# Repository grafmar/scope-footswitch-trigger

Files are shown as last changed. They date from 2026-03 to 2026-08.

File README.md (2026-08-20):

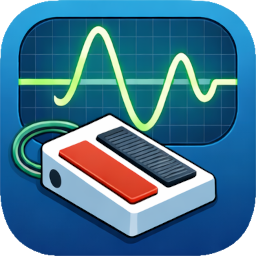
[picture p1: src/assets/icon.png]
Application icon
# Scope Footswitch Trigger 





Scope Footswitch Trigger enables hands-free control of an oscilloscope using a dual footswitch connected through an Arduino Nano.

The Arduino detects short and long presses on two foot pedals and sends events via USB (Serial) to a PC. A Python application running in the background receives these events and remotely controls the oscilloscope over LAN using SCPI commands.

This setup is ideal for lab environments where both hands are occupied — for example during probing, debugging hardware, or EMC measurements.

## 🧪 Usage
<p align="center">
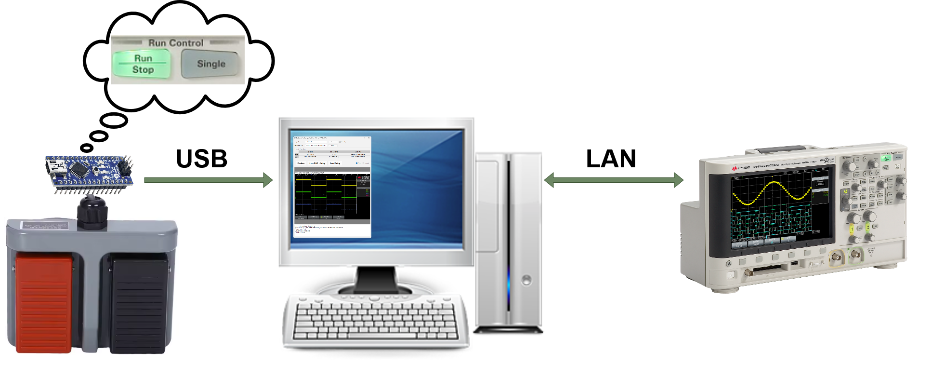
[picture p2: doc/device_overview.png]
Device overview
  
</p>

- Connect the dual footswitch to the PC via USB.
- Connect the oscilloscope to the network and obtain its IP address (via Utility → I/O on the Keysight/Agilent oscilloscope).
  - Activate VX11 on LeCroy oscilloscopes
- Start `OsciFootswitch.exe` (or `python OsciFootswitch.py`).
- Enter the oscilloscope’s IP address and click **\<Connect\>**.
- Use the "Identify Oscilloscope" checkbox to display a text box on the oscilloscope screen to verify the correct device.
- Select the correct serial port of the footswitch (identifier "USB-Serial CH340") and click **\<Open\>**.

→ The footswitch is ready.

## 🎯 Features
- Detects short and long presses for both pedals individually and if both are pressed at the same time
- Remote oscilloscope control via LAN
- Trigger control:
  - RUN / START
  - STOP
  - SINGLE (Single Shot)
- Toggle between:
  - Normal Trigger Mode
  - Auto Trigger Mode
- Capture and store:
  - Screenshot
  - Oscilloscope setup

## ⚙️ How It Works
1. The Arduino monitors two input pins connected to a dual footswitch.
2. Short and long presses are detected directly on the Arduino.
3. Events are sent via USB Serial (e.g. B1S, B1L, B2S, B2L, BBS, BBL).
4. The Python application:
  - Opens the configured serial port
  - Connects to the oscilloscope via IP (LAN)
  - Maps footswitch events to SCPI commands
5. The oscilloscope executes the corresponding trigger or screenshot command.

## 🤖 Hardware
A dual footswitch is connected to an Arduino Nano. The left switch connects to D3 and the right switch to D4 of the Arduino Nano. The switches connect to GND.

That's all for the hardware. The Arduino is powered and connected to a PC through its USB connector. [Detailed HW build](doc/hw/README.md) for more information.

The Arduino code `footswitch.ino` debounces the switch events, detects short and long presses and sends the corresponding event string through USB-serial.

<p align="center">
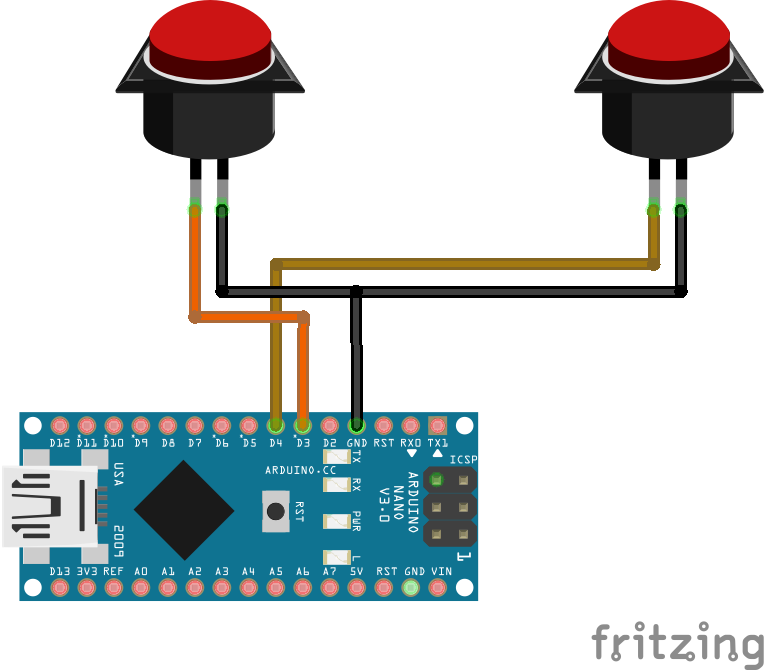
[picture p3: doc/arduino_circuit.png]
Hardware circuit
  
</p>

## 👨‍💻 Software
The PC application is compiled from a Ppython script. If you want to adapt the code, you have to install several Python packages, which are listed in `src/pc_app/requirements.txt`. You can apply them by:
```bash
pip install -r requirements.txt
```

To compile the Python to a Windows EXE file including all the necessary libraries you can simply execute the batch file:
```bash
.\src\build_scripts\build.bat
```
→ The EXE will be available at `.\src\build_scripts\dist\OsciFootswitch\OsciFootswitch.exe`

### 🏗️ SW-Architecture
<p align="center">
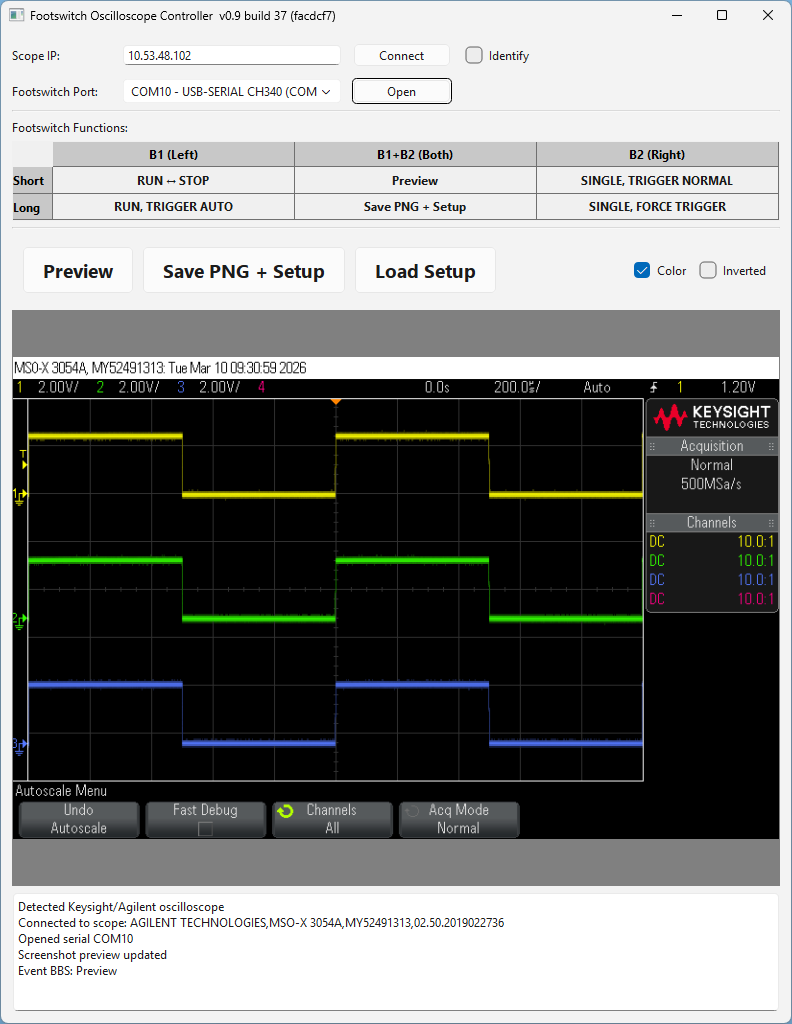
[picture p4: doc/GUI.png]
GUI
  
</p>
The GUI has the configuration part at the top, then a part that explains the footswitch function mappings. Below that is the screenshot section and at the bottom the log.

Upon connecting to the oscilloscope's IP the common SCPI/VISA identifier command `*IDN?` is used to identify the manufacturer and type of the oscilloscope. Depending on that identifier string the corresponding implementation for that oscilloscope is used. If the brand is not recognized the Keysight/Agilent implementation is used.

When the serial port of the footswitch is configured, the incoming events on the serial port are mapped to the corresponding oscilloscope functions and the SCPI/VISA commands are sent to the oscilloscope.

When a screenshot is captured, a setup file is also stored with the same basename. This setup file can then be reapplied to the scope later if needed.

### 📻 Supported Oscilloscopes
- ✅ Keysight/Agilent 2000 X-Series (DSOX2004A)
- ✅ Keysight/Agilent 3000 X-Series (MSOX3054A)
- ✅ Keysight/Agilent 4000 X-series (MSOX4024A)
- ✅ Keysight/Agilent 6000 X-series (DSOX6004A)
- ✅ Keysight/Agilent 7000 Series (MSO7054A)
- ✅ LeCroy Waverunner 6100
- ✅ LeCroy Waverunner 44XI
- ❌ Hameg/R&S HMO3000 Series (HMO3524) [documentation](doc/HMO3524_documentation.md)

SCPI/VISA Documentations:
- [2000 X-Series Programmer's Guide](https://www.keysight.com/us/en/assets/9018-06893/programming-guides/9018-06893.pdf)
- [3000 X-Series Programmer's Guide](https://www.keysight.com/us/en/assets/9018-06894/programming-guides/9018-06894.pdf)
- [4000 X-Series Programmer's Guide](https://www.keysight.com/us/en/assets/9018-06976/programming-guides/9018-06976.pdf)
- [6000 Series Programmer's Guide](https://www.keysight.com/ch/de/assets/9018-08107/programming-guides/9018-08107.pdf)
- [7000A Series Programmer's Guide](https://www.keysight.com/us/en/assets/9018-06630/programming-guides/9018-06630.pdf)
- [Waverunner Remote Control Manual](https://cdn.teledynelecroy.com/files/manuals/wr2_rcm_revb.pdf) 
- [Hameg/R&S HMO3000 Series SCPI Programmers Manual](https://www.batronix.com/files/Rohde-%26-Schwarz/Oscilloscope/HMO30xx/HMO3000_ProgrammingManual_en.pdf)

## 🚀 Advantages and Example Use Cases
- Hands-free operation → Trigger a single acquisition while holding probes
- Quickly toggle between Auto and Normal trigger during debugging
- Capture a screenshot including instrument setup without touching the scope
- Improve workflow in production test environments
- Minimal hardware cost
- Works in the background
- No modification of the oscilloscope required
- Fully scriptable and extendable

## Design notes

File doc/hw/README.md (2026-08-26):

# Footswitch Hardware

This project uses an off-the-shelf dual footswitch combined with an Arduino Nano to provide two USB-connected footswitch inputs for the PC application.

A custom 3D-printed enclosure houses the Arduino Nano and a small interface PCB and is mounted directly to the footswitch.

<p align="center">
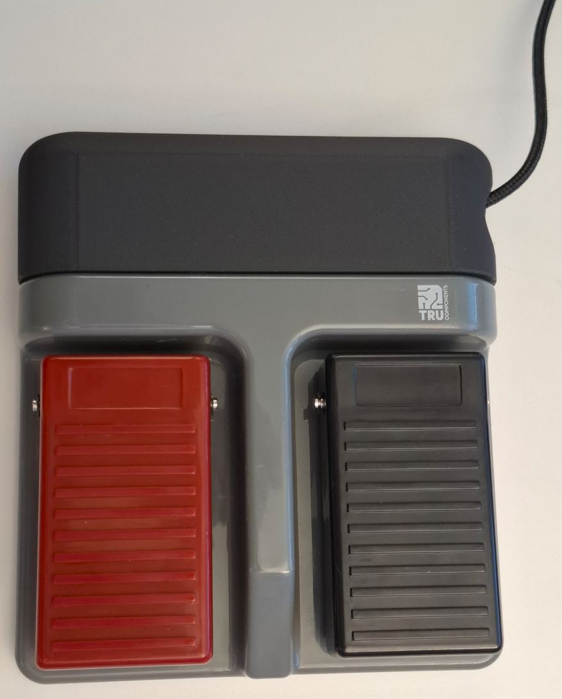
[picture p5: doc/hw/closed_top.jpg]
Footswitch – closed, top view
  
</p>

## Required Hardware

* Dual footswitch — TRU COMPONENTS TC-6648040, available from [Conrad.ch](https://www.conrad.ch/de/p/tru-components-fussschalter-250-v-ac-16-a-2-pedale-2-oeffner-2-schliesser-1-st-1662010.html)

  * Other similar dual footswitches can also be used, for example from [AliExpress](https://de.aliexpress.com/w/wholesale-double-footswitch.html)
* Arduino Nano
* Female pin headers for Arduino Nano
* Molex KK 254, 4-pin, right-angle header (Molex 22-05-7048)
* Matching Molex KK 254 connector housing with crimp contacts
* Stripboard / veroboard, or a custom PCB
* Wires
* M3 bolts and nuts
  * 4x M3x6 Cylinder Head
  * 4x M3x20 Cylinder Head
  * 2x M3x6 Lens Head
  * 2x M3 Lock Nut
* 8x Press-in threaded M3 inserts ([Bossard AG, 1386743, B3/BN1054](https://www.bossard.com/ch-en/eshop/threaded-inserts-for-press-in-for-plastic-materials/press-in-threaded-inserts-without-head-for-thermoplastics-and-thermosets/p/10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))

## Interface PCB

The PCB provides the electrical connection between the footswitch and the Arduino Nano.

It contains:

* A Molex KK 254 connector for the footswitch
* An Arduino Nano mounted on female pin headers
* Four mounting holes for attaching the PCB to the enclosure

The circuit is very simple:

| Arduino | Footswitch | Function |
| --- | --- | --- |
| D3 | Left switch (red) | Left pedal  |
| D4 | Right switch (black) | Right pedal |
| GND | Switch common | Ground |

Both switches connect their respective Arduino input to GND when pressed.

<p align="center">
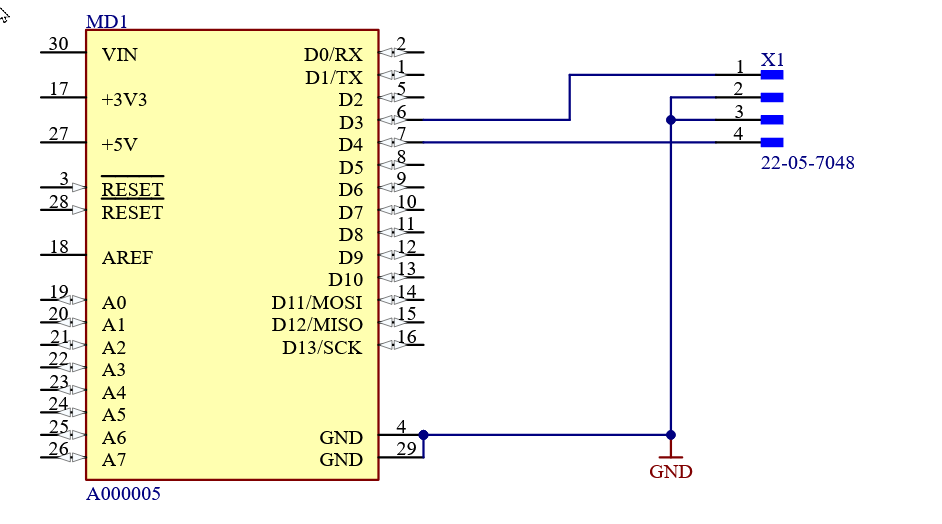
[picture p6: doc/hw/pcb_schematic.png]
PCB schematic
  
</p>

### Stripboard Version

The PCB can be built using a small piece of stripboard instead of a manufactured PCB. Nevertheless, if you want a manufactured PCB, here is the [fabrication data](../../hw/FAB-Labor_ScopeFootswitchTrigger-A0.zip).

When building the stripboard version, pay particular attention to the notch required for the screw that attaches the enclosure to the footswitch.

The following images show an example layout viewed from the top:

<p align="center">
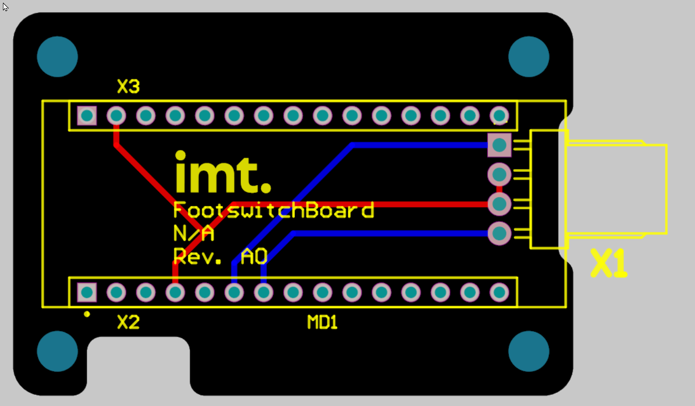
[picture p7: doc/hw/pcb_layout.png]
PCB layout
  
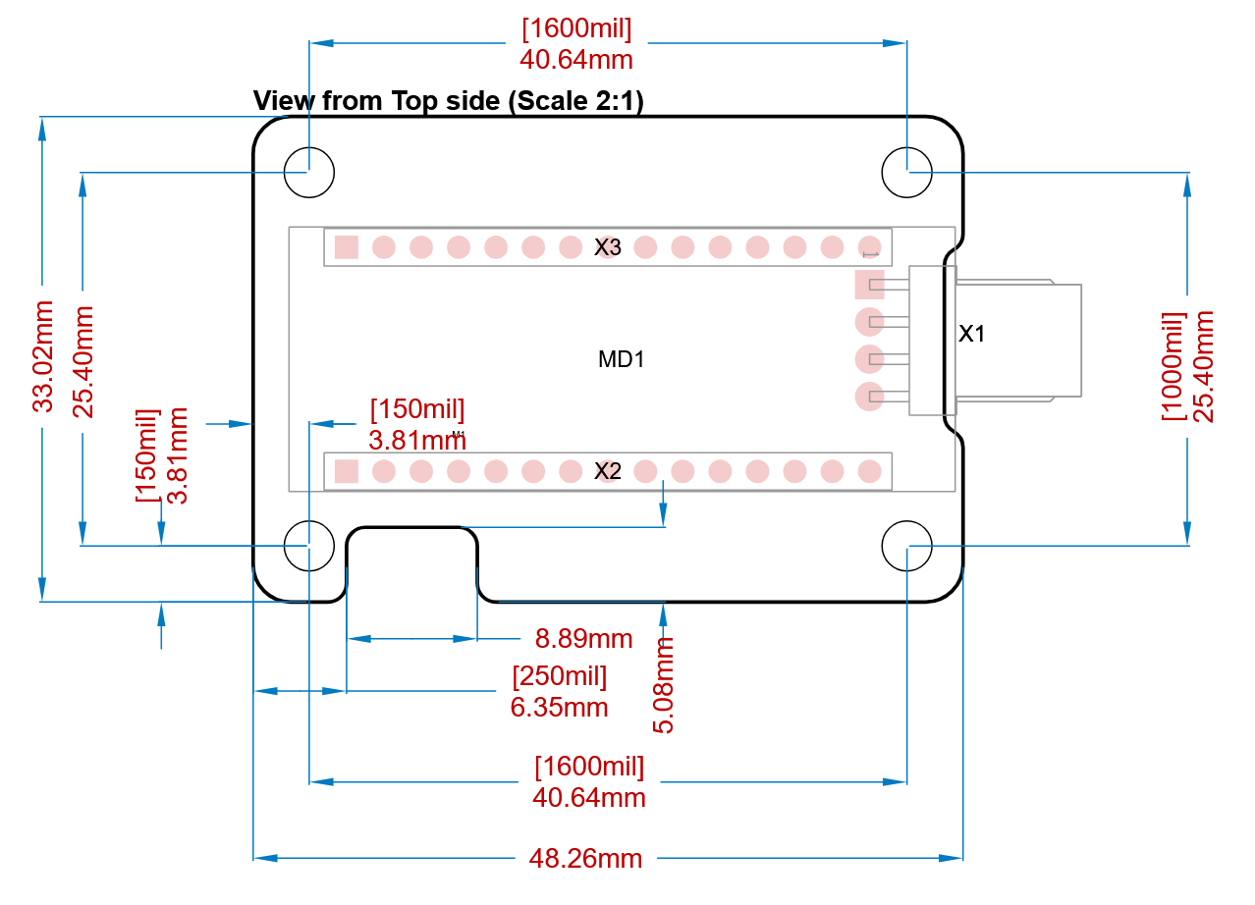
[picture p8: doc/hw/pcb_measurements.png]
PCB measurements
  
</p>
<p align="center">
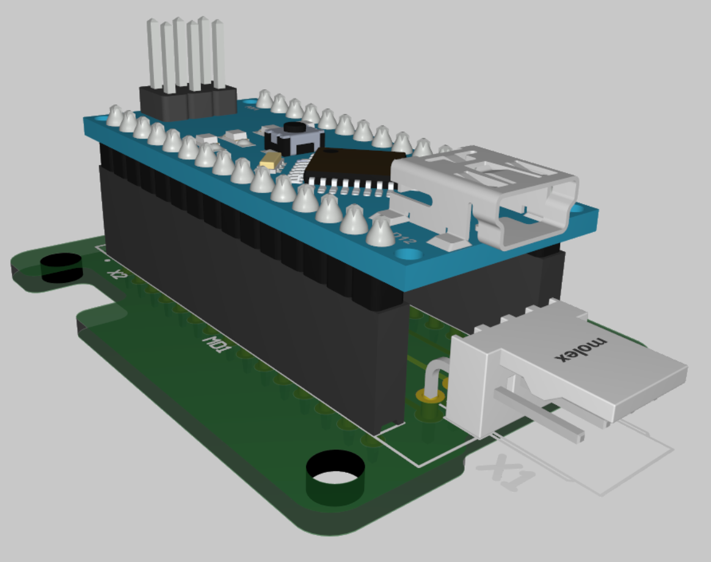
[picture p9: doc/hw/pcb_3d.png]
PCB 3D
  
</p>

## 3D-Printed Enclosure

The enclosure consists of a top and bottom part and is mounted directly to the footswitch using M3 bolts and nuts.

For the PCB and housing screws, the screw holes are designed for M3 heat-set threaded inserts. These inserts can be installed by gently melting them into the plastic using a soldering iron.

<p align="center">
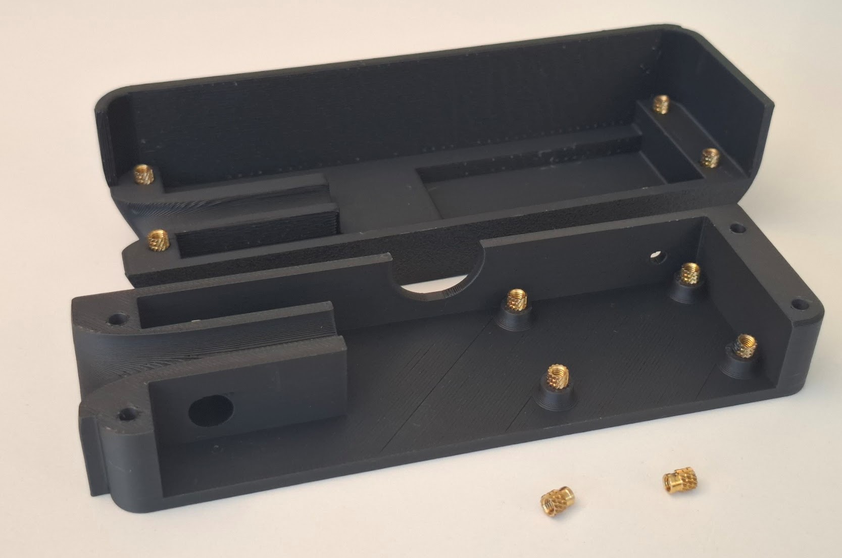
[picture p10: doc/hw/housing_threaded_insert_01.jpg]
Housing - Threaded Inserts Overview
  
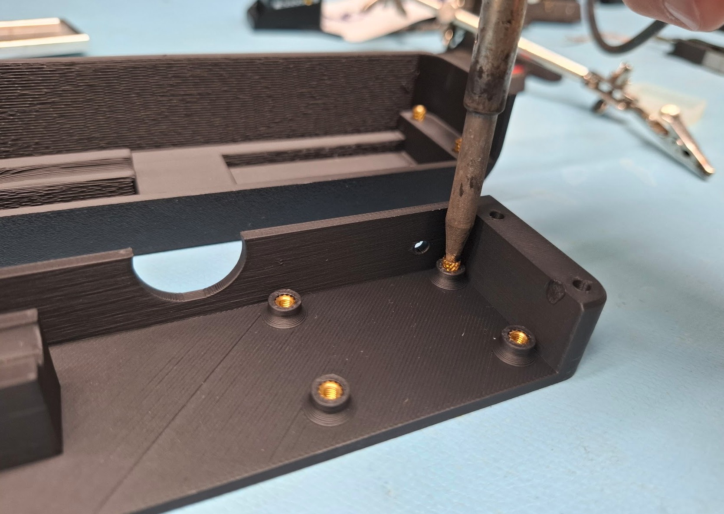
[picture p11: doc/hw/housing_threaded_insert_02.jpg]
Housing - Threaded Inserts Melting in
  
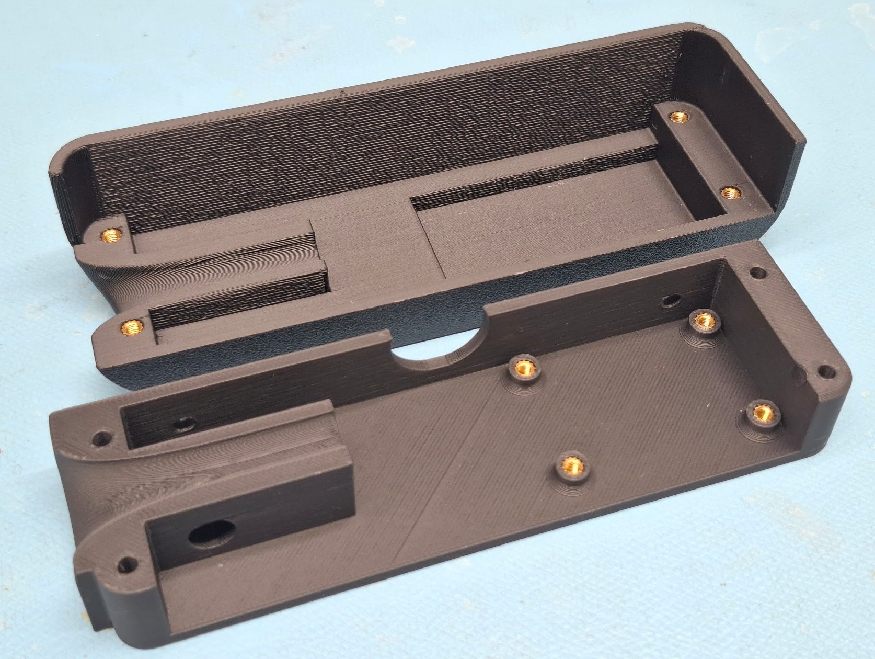
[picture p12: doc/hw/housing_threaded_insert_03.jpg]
Housing - Threaded Inserts Finished
  
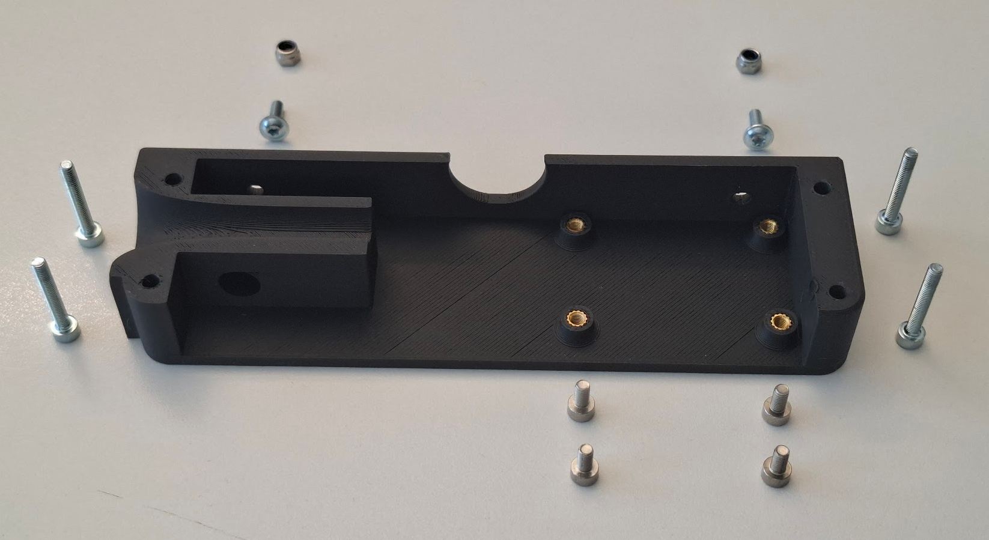
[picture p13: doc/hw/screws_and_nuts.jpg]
Screws and Nuts
  
</p>

Before mounting the enclosure, the required holes in the footswitch need to be drilled. A 3D-printed drilling jig is provided to simplify this process.

**Drilling jig:**
[OsciFootswitchHousing_DrillingJig.stl](../../housing/OsciFootswitchHousing_DrillingJig.stl)

The bottom part of the enclosure can then be mounted to the footswitch:

**Enclosure bottom:**
[OsciFootswitchHousing-BaseBodyBottom.stl](../../housing/OsciFootswitchHousing-BaseBodyBottom.stl)

The top part is attached to the bottom part using M3 bolts:

**Enclosure top:**
[OsciFootswitchHousing-BaseBodyTop.stl](../../housing/OsciFootswitchHousing-BaseBodyTop.stl)

## Assembly

The wires are soldered directly to the two footswitches and terminated with crimp contacts for the Molex KK 254 connector.

The connector is then plugged into the interface PCB, which is mounted inside the bottom part of the enclosure.

After connecting the USB cable to the Arduino Nano, the cable can be secured with a zip tie to provide strain relief.

Finally, the enclosure can be closed using the M3 bolts.

<p align="center">
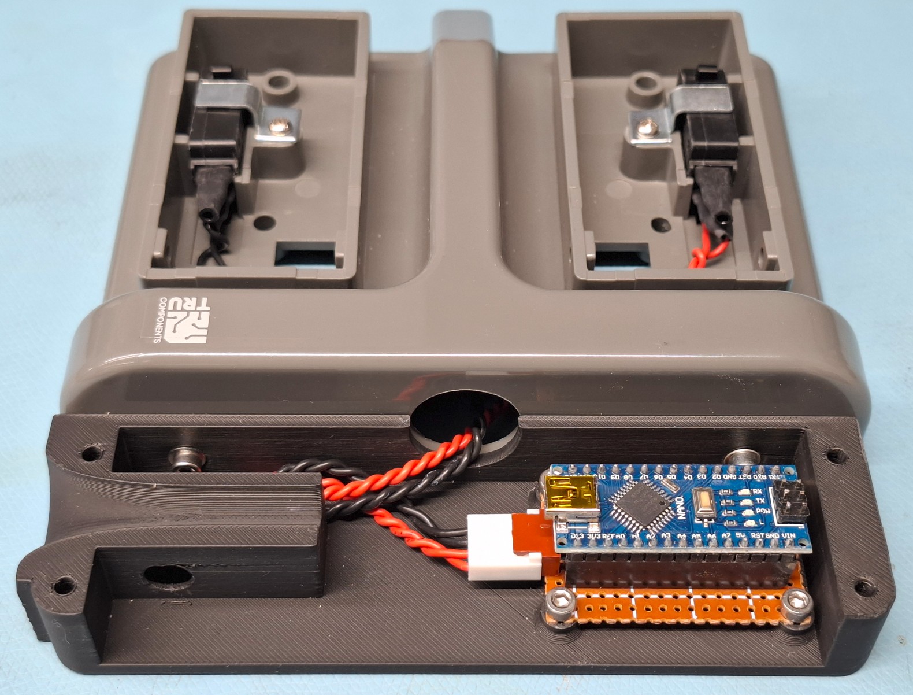
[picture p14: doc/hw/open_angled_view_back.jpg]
Footswitch – rear angled view
  
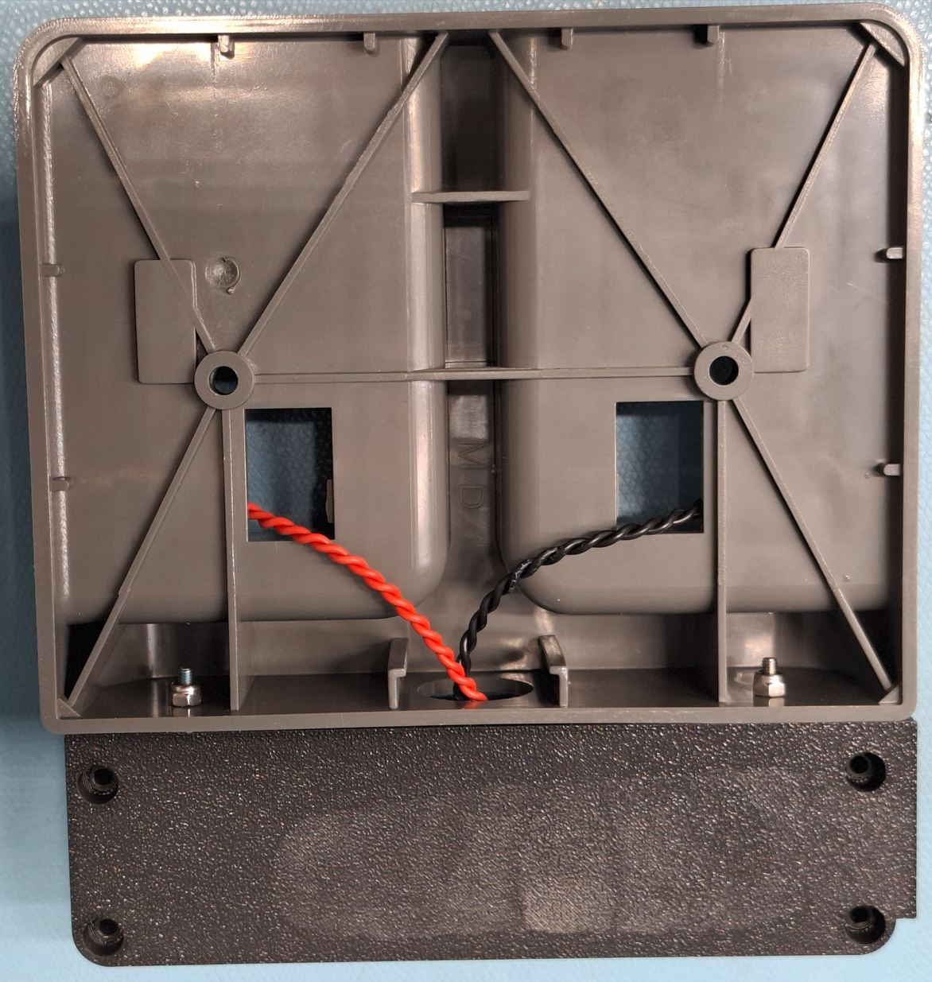
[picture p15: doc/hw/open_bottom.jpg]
Footswitch – bottom view
  
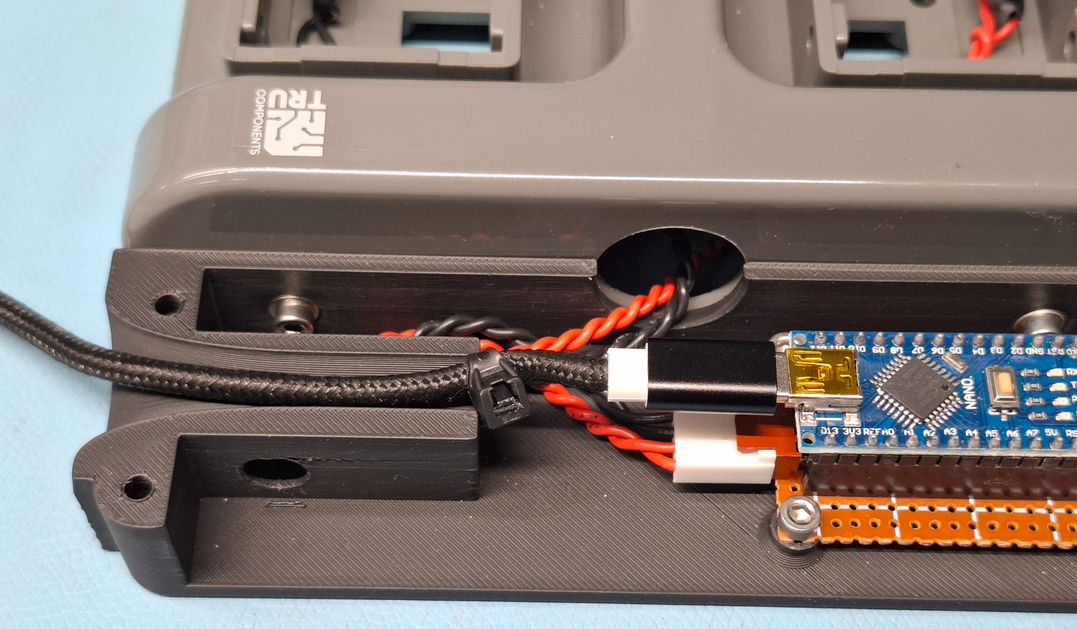
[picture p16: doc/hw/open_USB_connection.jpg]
USB connection
  
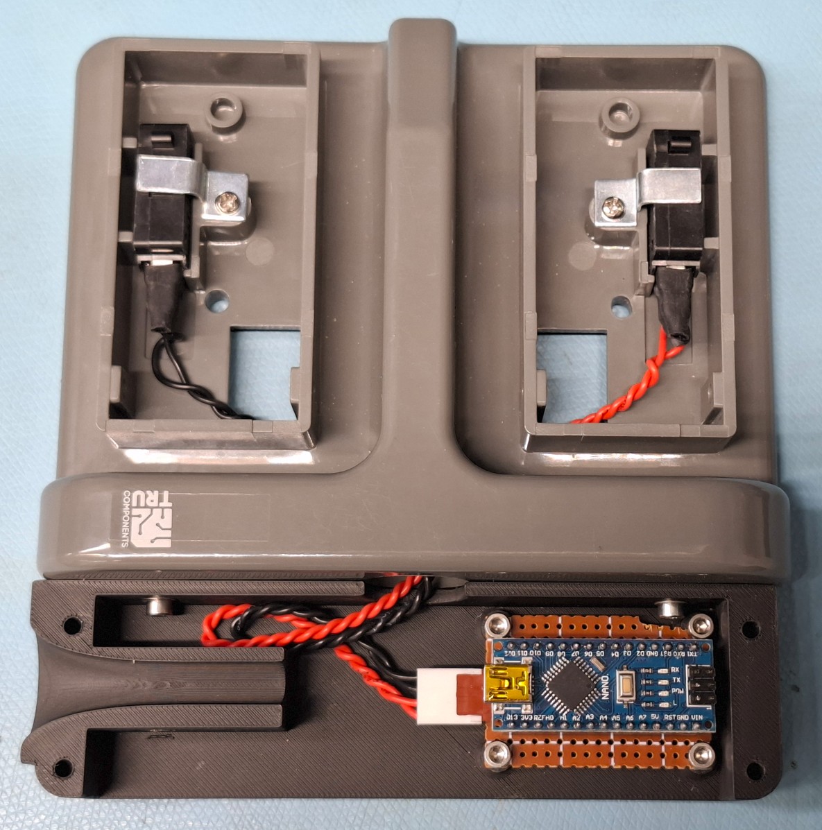
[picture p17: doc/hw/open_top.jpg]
Footswitch – top view
  
</p>

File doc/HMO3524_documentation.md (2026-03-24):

# HMO3524

## Overview
The available **HMO3524 oscilloscope** is an early hardware/firmware revision.  
Support from Hameg respectively Rhode & Schwarz for this version is very limited.

Older firmware versions and corresponding documentation are:
- difficult to find  
- often not publicly available  

As a result, reverse engineering and testing were required to evaluate SCPI support.

---

## SCPI Investigation

A custom script (`hameScpiChecker.py`) was used to:

- test known SCPI commands  
- probe undocumented commands  
- identify supported vs. unsupported functionality  

### Findings

- Only a **very limited subset of SCPI commands** is supported  
- Many standard commands (e.g. `RUN`, `STOP`, `SINGLE`) are:
  - not implemented, or  
  - ignored without proper error reporting  

- Some commands (e.g. `ACQ:TYPE`, partial `TRIG` queries) work inconsistently  

---

## Connectivity

Unlike most modern oscilloscopes, this device:

- ❌ does **not support standard VISA INSTR connections**
- ✅ is only accessible via **raw TCP socket**: `TCPIP::<IP>::50000::SOCKET`

This also leads to:

- unreliable SCPI responses  
- inconsistent error handling (`SYST:ERR?`)  
- missing or partial query replies  

---

## Conclusion

Due to the limitations:

- missing essential SCPI commands (RUN/STOP/SINGLE)  
- unreliable communication over TCP socket  
- incomplete firmware implementation  

👉 **This oscilloscope is not supported by this project.**

---

## Device Information

| Parameter | Value |
|---|---|
| Device Class | Oscilloscope |
| Device Type | HMO3524 |
| Firmware Version  | 01.020 |
| Interface Type | HO730 |
| HW Version | 1.001 |
| SW Version | 2.000 |

---

## Test Script

Script used for testing:
[```hamegScpiChecker.py```](hamegScpiChecker.py)

---

## Script Output

```text
>>> CLEAR ERRORS (*CLS)

============================================================
IDENTIFICATION
============================================================

>>> QUERY: *IDN?
<<< RESPONSE: HAMEG,HMO3524,056270075,HW10110000,SW01.020
>>> QUERY: SYST:ERR:ALL?
<<< ERRORS: 0,"No error"

============================================================
TRIGGER
============================================================

>>> WRITE: TRIG:A:MODE AUTO
>>> QUERY: SYST:ERR:ALL?
<<< ERRORS: 0,"No error"

>>> QUERY: TRIG:A:MODE?
<<< RESPONSE: AUTO
>>> QUERY: SYST:ERR:ALL?
<<< ERRORS: 0,"No error"

>>> WRITE: TRIG:A:MODE NORM
>>> QUERY: SYST:ERR:ALL?
ERR QUERY FAILED: VI_ERROR_TMO (-1073807339): Timeout expired before operation completed.

>>> QUERY: TRIG:A:MODE?
<<< RESPONSE: AUTO
>>> QUERY: SYST:ERR:ALL?
<<< ERRORS: -221,"Settings conflict",-101,"Invalid character",-101,"Invalid character",-101,"Invalid character",-113,"Undefined header"

============================================================
ACQ TYPE (WORKING)
============================================================

>>> QUERY: ACQ:TYPE?
<<< RESPONSE: ROLL
>>> QUERY: SYST:ERR:ALL?
<<< ERRORS: 0,"No error"

>>> WRITE: ACQ:TYPE ROLL
>>> QUERY: SYST:ERR:ALL?
<<< ERRORS: 0,"No error"

>>> QUERY: ACQ:TYPE?
<<< RESPONSE: ROLL
>>> QUERY: SYST:ERR:ALL?
<<< ERRORS: 0,"No error"

>>> WRITE: ACQ:TYPE REFresh
>>> QUERY: SYST:ERR:ALL?
<<< ERRORS: 0,"No error"

>>> QUERY: ACQ:TYPE?
<<< RESPONSE: REFR
>>> QUERY: SYST:ERR:ALL?
<<< ERRORS: 0,"No error"

============================================================
ACQ STATE (SHOULD WORK)
============================================================

>>> QUERY: ACQ:STATE?
QUERY ERROR: VI_ERROR_TMO (-1073807339): Timeout expired before operation completed.
>>> QUERY: SYST:ERR:ALL?
<<< ERRORS: -101,"Invalid character"

>>> WRITE: ACQ:STATE RUN
>>> QUERY: SYST:ERR:ALL?
<<< ERRORS: -101,"Invalid character"

>>> WRITE: ACQ:STATE STOP
>>> QUERY: SYST:ERR:ALL?
<<< ERRORS: -101,"Invalid character"

============================================================
RUN / STOP (CLASSIC)
============================================================

>>> WRITE: RUN
>>> QUERY: SYST:ERR:ALL?
<<< ERRORS: -101,"Invalid character"

>>> WRITE: STOP
>>> QUERY: SYST:ERR:ALL?
<<< ERRORS: -101,"Invalid character",-101,"Invalid character"

>>> WRITE: RUNSingle
>>> QUERY: SYST:ERR:ALL?
<<< ERRORS: -101,"Invalid character"

>>> WRITE: RUNSINGLE
>>> QUERY: SYST:ERR:ALL?
<<< ERRORS: -101,"Invalid character"

>>> WRITE: SINGLE
>>> QUERY: SYST:ERR:ALL?
<<< ERRORS: -101,"Invalid character",-101,"Invalid character"

>>> WRITE: SINGle
>>> QUERY: SYST:ERR:ALL?
<<< ERRORS: -101,"Invalid character",-101,"Invalid character"

============================================================
SINGLE / STOPAFTER
============================================================

>>> WRITE: ACQ:A:STOPAFTER SEQ
>>> QUERY: SYST:ERR:ALL?
<<< ERRORS: -113,"Undefined header",-101,"Invalid character"

>>> WRITE: ACQ:A:STATE RUN
>>> QUERY: SYST:ERR:ALL?
<<< ERRORS: -113,"Undefined header",-101,"Invalid character"

============================================================
SCREENSHOT
============================================================

>>> QUERY: HCOPy:DATA?
QUERY ERROR: 'ascii' codec can't decode byte 0x80 in position 26: ordinal not in range(128)
>>> QUERY: SYST:ERR:ALL?
<<< ERRORS: 0,"No error"

============================================================
OVERVIEWS of different parts
============================================================

>>> QUERY: ACQ?
<<< RESPONSE: :ACQ:TYPE REFR;:ACQ:AVER:COUN 2.0E+00;:ACQ:REAL ON;:ACQ:PEAK OFF;:ACQ:HRES OFF;:ACQ:WRAT AUTO
>>> QUERY: SYST:ERR:ALL?
<<< ERRORS: 0,"No error"

>>> QUERY: TRIG?
<<< RESPONSE: :TRIG:A:MODE NORM;:TRIG:A:TYPE EDGE;:TRIG:A:EDGE:SOUR CH1;:TRIG:A:EDGE:SLOP POS;:TRIG:A:EDGE:COUP DC;:TRIG:A:EDGE:LEV 0.0E+00;:TRIG:A:EDGE:FILT:LPAS OFF;:TRIG:A:EDGE:FILT:NREJ ON;:TRIG:A:VID:FIEL ALL;:TRIG:A:VID:LINE 0.0E+00;:TRIG:A:VID:POL POS;:TRIG:A:VID:STAN PAL;:TRIG:A:VID:SOUR CH1;:TRIG:B:STAT OFF;:TRIG:B:LEV 0.0E+00
>>> QUERY: SYST:ERR:ALL?
<<< ERRORS: 0,"No error"

>>> QUERY: HCOP?
<<< RESPONSE: :HCOP:FORM BMP;:HCOP:SIZE:X 640;:HCOP:SIZE:Y 520
>>> QUERY: SYST:ERR:ALL?
<<< ERRORS: 0,"No error"

>>> QUERY: SYST?
<<< RESPONSE: :SYST:NAME ""
>>> QUERY: SYST:ERR:ALL?
<<< ERRORS: 

DONE.
```

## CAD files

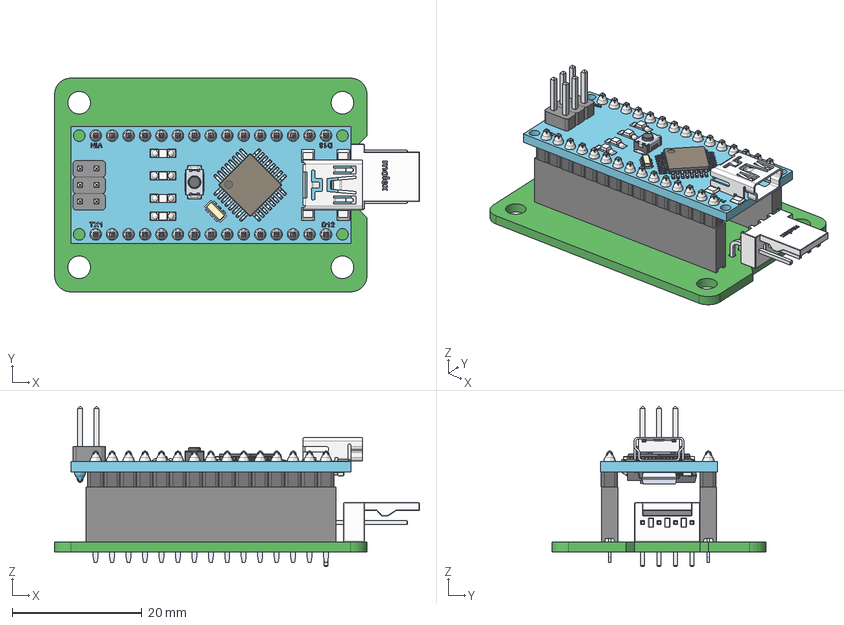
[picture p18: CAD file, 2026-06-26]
housing/Labor_ScopeFootswitchTrigger.step
56.3 x 33.0 x 24.7 mm
PPTC151LFBN-RC--3DModel-STEP-56544 x 2
22057048_Tin
Molex
Pin1_Triangle
MINIUSBSHELL
MINI USB SOLDER
reset core
reset shell
nano-board
2pin_header__02 x 3
15pin_header__ x 2
atmega328
ftdi FT232rl
smt_resistor222
led x 4
16mhz crystal - measured
cap106C
nano - reg
NANO DIODE
189 RESISTOR PACK

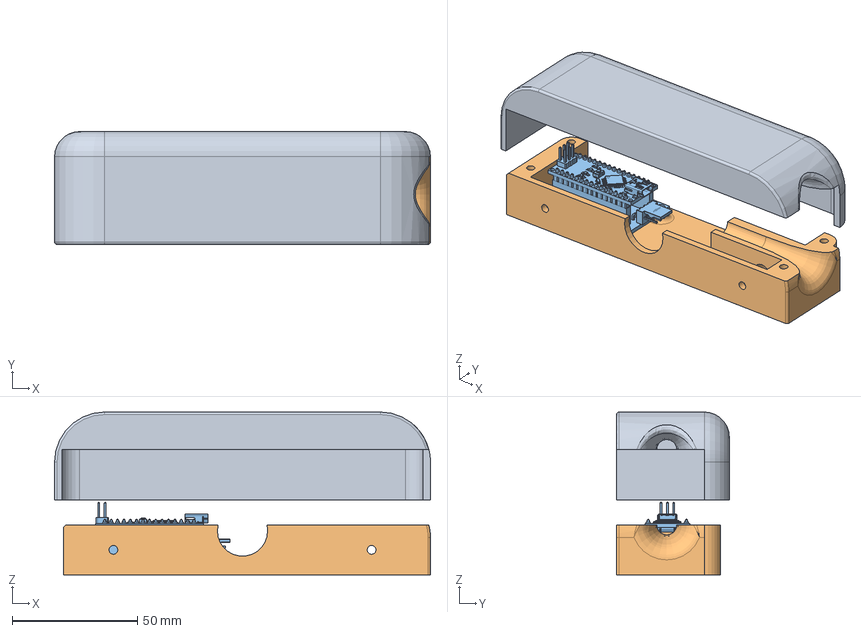
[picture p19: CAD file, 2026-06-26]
housing/OsciFootswitchHousing.FCStd
150.0 x 45.0 x 65.0 mm
BaseBodyTop
BaseBodyBottom
Labor_ScopeFootswitchTrigger

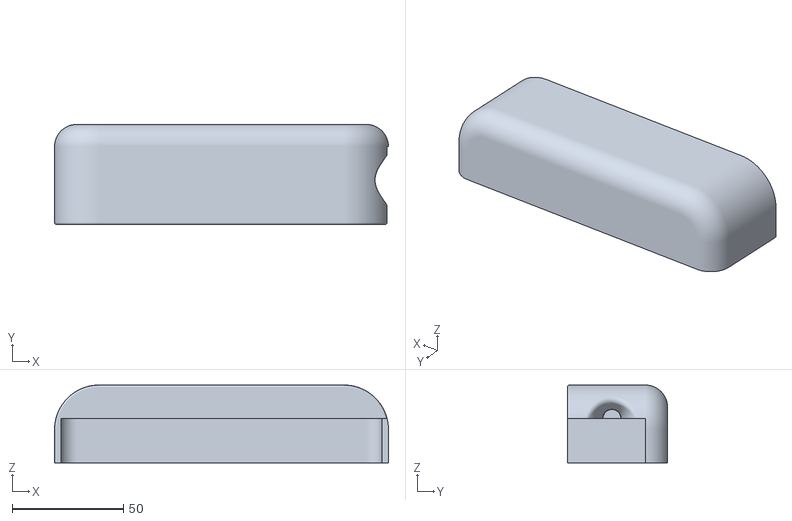
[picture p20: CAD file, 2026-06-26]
housing/OsciFootswitchHousing-BaseBodyTop.stl
150.0 x 45.0 x 35.0

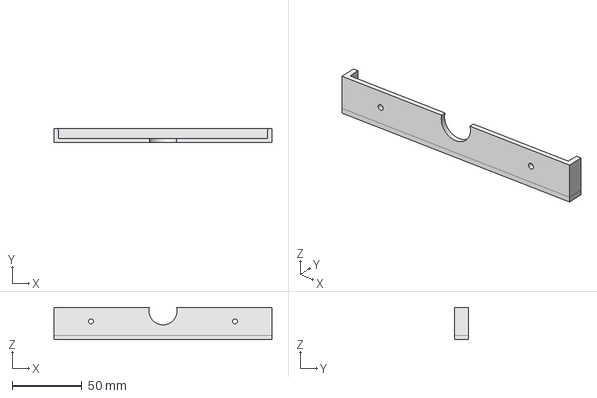
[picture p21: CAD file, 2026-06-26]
housing/OsciFootswitchHousing_DrillingJig.FCStd
156.0 x 10.0 x 23.0 mm

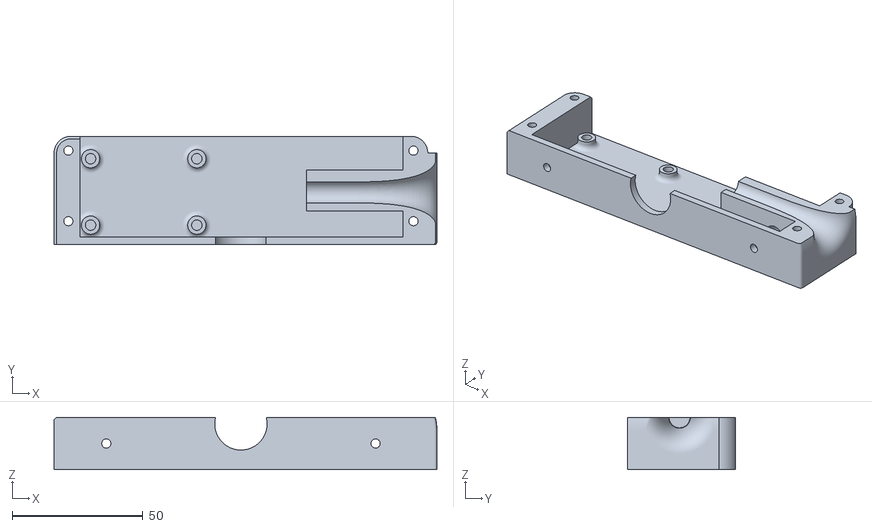
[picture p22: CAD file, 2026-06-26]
housing/OsciFootswitchHousing-BaseBodyBottom.stl
146.5 x 41.5 x 20.0

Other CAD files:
housing/OsciFootswitchHousing_DrillingJig.stl

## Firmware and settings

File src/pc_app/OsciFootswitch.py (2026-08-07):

import os
import sys
import threading
import queue
import subprocess
import serial
import serial.tools.list_ports
import time
import pyvisa

from PySide6.QtCore import Qt, QTimer
from PySide6.QtGui import QPixmap, QFont, QIcon
from PySide6.QtWidgets import (
    QApplication, QLayout, QWidget, QLabel, QPushButton, QVBoxLayout,
    QHBoxLayout, QComboBox, QLineEdit, QCheckBox, QTextEdit,
    QTableWidget, QTableWidgetItem, QHeaderView, QFileDialog,
    QSizePolicy, QGridLayout, QFrame
)

# Oscilloscope Implementations
from scopes.base import BaseScope
from scopes.keysight import KeysightScope
from scopes.keysight7000 import Keysight7000Scope
from scopes.lecroy import LeCroyScope


# ----------------------------
# Version
# ----------------------------

APP_VERSION = "1.2"

def get_git_version():
    try:
        commit = subprocess.check_output(
            ["git", "rev-parse", "--short", "HEAD"],
            stderr=subprocess.DEVNULL
        ).decode().strip()

        count = subprocess.check_output(
            ["git", "rev-list", "--count", "HEAD"],
            stderr=subprocess.DEVNULL
        ).decode().strip()

        return f"{APP_VERSION} build {count} ({commit})"
    except:
        return APP_VERSION

VERSION = get_git_version()

# ----------------------------
# Serial Reader Thread
# ----------------------------
class SerialReader(threading.Thread):
    def __init__(self, port, baudrate, event_queue):
        super().__init__(daemon=True)
        self.port = port
        self.baudrate = baudrate
        self.queue = event_queue
        self._running = True
        self.ser = None

    def run(self):
        try:
            self.ser = serial.Serial(self.port, self.baudrate, timeout=1)
            while self._running:
                line = self.ser.readline().decode(errors="ignore").strip()
                if line:
                    self.queue.put(line)
        except Exception as e:
            self.queue.put(f"ERROR:{e}")

    def stop(self):
        self._running = False
        if self.ser:
            try:
                self.ser.cancel_read()
            except:
                pass
            self.ser.close()

# ============================================================
# Scope Controller (Factory + Delegation)
# ============================================================

class ScopeController:
    def __init__(self, log_callback=None):
        self.rm = pyvisa.ResourceManager("@py")
        self.scope = None
        self.device: BaseScope | None = None
        self.log = log_callback or (lambda msg: None)

        # schützt VISA Zugriff gegen parallele Threads
        self.lock = threading.Lock()

        self.keep_alive_running = True
        self.keep_alive_thread = threading.Thread(
            target=self._keep_alive_loop,
            daemon=True
        )
        self.keep_alive_thread.start()

    def connect(self, ip):
        with self.lock:
            self.scope = self.rm.open_resource(f"TCPIP0::{ip}::INSTR")
            self.scope.timeout = 5000

            idn = self.scope.query("*IDN?")
            idn_u = idn.upper()

            if "LECROY" in idn_u:
                self.device = LeCroyScope(self.scope, self.log)
                self.log("Detected LeCroy oscilloscope")

            elif "KEYSIGHT" in idn_u or "AGILENT" in idn_u:
                
                if "MSO70" in idn_u or "DSO70" in idn_u:
                    self.device = Keysight7000Scope(self.scope, self.log)
                    self.log("Detected Keysight/Agilent 7000oscilloscope")

                else:
                    self.device = KeysightScope(self.scope, self.log)
                    self.log("Detected Keysight/Agilent oscilloscope")

            else:
                self.device = KeysightScope(self.scope, self.log)
                self.log("Unknown oscilloscope. Using Keysight/Agilent commands as default.")

            return idn

    # ---------- Keep Alive ----------

    def _keep_alive_loop(self):
        while self.keep_alive_running:
            time.sleep(10)
            if self.scope is None:
                continue
            try:
                with self.lock:
                    self.scope.query("*IDN?")

            except Exception as e:
                self.log(f"Scope connection lost: {e}")
                self._disconnect()

    def _disconnect(self):
        with self.lock:
            try:
                if self.scope:
                    self.scope.close()

            except Exception:
                pass

            self.scope = None
            self.device = None

        self.log("Scope disconnected")

    # ---------- Device Check ----------

    def _require_device(self) -> bool:
        if not self.device:
            self.log("Scope not connected")
            return False
        return True
        
    # ---------- Delegation ----------

    def identify(self, enable):
        if not self._require_device():
            return
        with self.lock:
            self.device.identify(enable)

    def run(self):
        if not self._require_device():
            return
        with self.lock:
            self.device.run()

    def stop(self):
        if not self._require_device():
            return
        with self.lock:
            self.device.stop()

    def single(self):
        if not self._require_device():
            return
        with self.lock:
            self.device.single()

    def trigger_auto(self):
        if not self._require_device():
            return
        with self.lock:
            self.device.trigger_auto()

    def trigger_force(self):
        if not self._require_device():
            return
        with self.lock:
            self.device.trigger_force()

    def trigger_normal(self):
        if self._require_device():
            with self.lock:
                self.device.trigger_normal()

    def is_running(self):
        if not self._require_device():
            return False
        with self.lock:
            return self.device.is_running()

    def get_screenshot_png(self, color, inverted):
        if not self._require_device():
            return None
        with self.lock:
            return self.device.get_screenshot_png(color, inverted)

    def get_setup(self) -> bytes:
        if not self._require_device():
            return b""
        with self.lock:
            return self.device.get_setup()

    def write_setup_data(self, data: bytes) -> bool:
        if not self._require_device():
            return False
        with self.lock:
            return self.device.write_setup_data(data)
        
# ----------------------------
# Serial ports dropdown
# ----------------------------
class SerialPortComboBox(QComboBox):
    def __init__(self, refresh_callback, parent=None):
        super().__init__(parent)
        self.refresh_callback = refresh_callback

    def showPopup(self):
        self.refresh_callback()
        super().showPopup()



# ----------------------------
# path finder for assets (icon)
# ----------------------------
def resource_path(relative):
    if hasattr(sys, "_MEIPASS"):
        return os.path.join(sys._MEIPASS, relative)
    return os.path.join(os.path.abspath("."), relative)

# ----------------------------
# Main GUI
# ----------------------------
class MainWindow(QWidget):
    def __init__(self):
        super().__init__()
        self.setWindowIcon(QIcon(resource_path("icon.ico")))
        self.setWindowTitle(f"Footswitch Oscilloscope Controller  v{VERSION}")

        self.event_queue = queue.Queue()
        self.serial_thread = None
        self.scope = ScopeController(self.log_msg)

        self.init_ui()
        self.refresh_serial_ports()

        self.timer = QTimer()
        self.timer.timeout.connect(self.process_events)
        self.timer.start(50)

    def init_ui(self):
        layout = QVBoxLayout()
        layout.setHorizontalSizeConstraint(QLayout.SetMinimumSize)

        config_layout = QGridLayout()
        config_layout.setHorizontalSpacing(10)
        config_layout.setVerticalSpacing(10)

        # ---- Labels (gleich breit) ----
        label_width = 100

        scope_label = QLabel("Scope IP:")
        scope_label.setFixedWidth(label_width)

        serial_label = QLabel("Footswitch Port:")  # besser als "Serial Port"
        serial_label.setFixedWidth(label_width)

        # ---- Scope Row ----
        self.ip_edit = QLineEdit("10.53.48.1")
        self.connect_btn = QPushButton("Connect")
        self.connect_btn.clicked.connect(self.connect_scope)

        self.identify_cb = QCheckBox("Identify")
        self.identify_cb.toggled.connect(self.identify_scope)

        # ---- Serial Row ----
        self.serial_combo = SerialPortComboBox(self.refresh_serial_ports)
        self.open_serial_btn = QPushButton("Open")
        self.open_serial_btn.clicked.connect(self.open_serial)

        # ---- Buttons gleich breit ----
        button_width = 100
        self.connect_btn.setFixedWidth(button_width)
        self.open_serial_btn.setFixedWidth(button_width)

        # ---- Inputs gleich breit ----
        input_width = 220
        self.ip_edit.setFixedWidth(input_width)
        self.serial_combo.setFixedWidth(input_width)

        # ---- Grid anordnen ----
        config_layout.addWidget(scope_label,        0, 0)
        config_layout.addWidget(self.ip_edit,       0, 1)
        config_layout.addWidget(self.connect_btn,   0, 2)
        config_layout.addWidget(self.identify_cb,   0, 3)

        config_layout.addWidget(serial_label,       1, 0)
        config_layout.addWidget(self.serial_combo,  1, 1)
        config_layout.addWidget(self.open_serial_btn, 1, 2)

        layout.addLayout(config_layout)

        # ---- Separator ----
        separator = QFrame()
        separator.setFrameShape(QFrame.HLine)
        separator.setFrameShadow(QFrame.Sunken)
        separator.setMaximumWidth(768)
        layout.addWidget(separator)

        # --- Footswitch Table ---
        layout.addWidget(QLabel("Footswitch Functions:"))
        self.table = QTableWidget(2, 3)
        self.table.setHorizontalHeaderLabels(["B1 (Left)", "B1+B2 (Both)", "B2 (Right)"])
        self.table.setVerticalHeaderLabels(["Short", "Long"])
        self.table.setEditTriggers(QTableWidget.NoEditTriggers)
        self.table.setSelectionMode(QTableWidget.NoSelection)
        self.table.setFocusPolicy(Qt.NoFocus)

        # -------- Layout behaviour --------
        header = self.table.horizontalHeader()
        header.setSectionResizeMode(QHeaderView.Stretch)  # alle Spalten gleich breit
        self.table.verticalHeader().setSectionResizeMode(QHeaderView.Stretch)
        self.table.setStyleSheet("""
        /* Tabelle */
        QTableWidget {
            background-color: #f0f0f0;        /* same color as  GUI */
            gridline-color: #707070;          /* darker Gridlines */
            border: 1px solid #707070;
        }

        /* Horizontal + Vertical Header */
        QHeaderView::section {
            background-color: #c8c8c8;        /* Header gray */
            color: black;
            font-weight: bold;
            border: 0px solid #707070;        /* darker lines also here */
            border-right: 1px solid #707070;
            border-bottom: 1px solid #707070;
        }

        /* Top-Left Corner */
        QTableCornerButton::section {
            background-color: #f0f0f0;        /* same color as Header */
            border: 0px solid #707070;        /* darker lines also here */
        }
        """)

        # -------- Schrift fett --------
        bold_font = QFont()
        bold_font.setBold(True)

        def set_item(row, col, text):
            item = QTableWidgetItem(text)
            item.setTextAlignment(Qt.AlignCenter)  # zentriert
            item.setFont(bold_font)                # fett
            self.table.setItem(row, col, item)

        set_item(0, 0, "RUN ↔ STOP")
        set_item(0, 1, "Preview")
        set_item(0, 2, "SINGLE, TRIGGER NORMAL")
        set_item(1, 0, "RUN, TRIGGER AUTO")
        set_item(1, 1, "Save PNG + Setup")
        set_item(1, 2, "SINGLE, FORCE TRIGGER")

        # add click event to table cells
        self.table.cellClicked.connect(self.footswitch_cell_clicked)

        layout.addWidget(self.table)

        # Tabelle fixieren (keine vertikale Skalierung)
        self.table.setFixedHeight(80)  # passt für 2 Zeilen
        self.table.setFixedWidth(768)
        self.table.setSizePolicy(QSizePolicy.Fixed, QSizePolicy.Fixed)

        # ---- Separator ----
        separator = QFrame()
        separator.setFrameShape(QFrame.HLine)
        separator.setFrameShadow(QFrame.Sunken)
        separator.setMaximumWidth(768)
        layout.addWidget(separator)

        # --- Screenshot Controls ---
        shot_widget = QWidget()
        shot_widget.setFixedWidth(768)
        shot_layout = QHBoxLayout(shot_widget)

        # Preview Screenshot
        self.preview_btn = QPushButton("Preview")
        self.preview_btn.clicked.connect(self.preview_screenshot)
        self.preview_btn.setMinimumHeight(50)  # doppelte Höhe
        self.preview_btn.setStyleSheet("font-size: 14pt; font-weight: bold; padding: 5px 20px;")
        shot_layout.addWidget(self.preview_btn)

        # Save PNG + Setup
        self.save_btn = QPushButton("Save PNG + Setup")
        self.save_btn.clicked.connect(self.save_screenshot_and_setup)
        self.save_btn.setMinimumHeight(50)
        self.save_btn.setStyleSheet("font-size: 14pt; font-weight: bold; padding: 5px 20px;")
        shot_layout.addWidget(self.save_btn)

        # Load Setup
        self.load_setup_btn = QPushButton("Load Setup")
        self.load_setup_btn.clicked.connect(self.load_setup)
        self.load_setup_btn.setMinimumHeight(50)
        self.load_setup_btn.setStyleSheet("font-size: 14pt; font-weight: bold; padding: 5px 20px;")
        shot_layout.addWidget(self.load_setup_btn)

        # Spacer, damit rechts nichts wackelt
        shot_layout.addStretch()

        # --- Color / Invert Checkboxes rechts, enger zusammen ---
        cb_layout = QHBoxLayout()
        self.color_cb = QCheckBox("Color")
        self.color_cb.setChecked(True)
        cb_layout.addWidget(self.color_cb)

        self.invert_cb = QCheckBox("Inverted")
        cb_layout.addWidget(self.invert_cb)

        cb_layout.setSpacing(5)  # enger zusammen
        shot_layout.addLayout(cb_layout)

        layout.addWidget(shot_widget)

        # --- Preview Label ---
        self.image_label = QLabel()
        self.image_label.setAlignment(Qt.AlignCenter)
        self.image_label.setFixedSize(768, 576)  # 4:3 Verhältnis
        self.image_label.setStyleSheet("border: 1px solid gray; background-color: gray;")
        layout.addWidget(self.image_label)

        # --- Log ---
        self.log = QTextEdit()
        self.log.setReadOnly(True)
        self.log.setFixedWidth(768)
        self.log.setMinimumHeight(6 * 20) # 6 Zeilen à ca. 20px pro Zeile
        self.log.setSizePolicy(QSizePolicy.Fixed, QSizePolicy.Expanding)
        layout.addWidget(self.log)

        self.setLayout(layout)

    # ---------- Helpers ----------

    def refresh_serial_ports(self):
        self.serial_combo.clear()
        for port in serial.tools.list_ports.comports():
            self.serial_combo.addItem(
                f"{port.device} - {port.description}", port.device
            )

    # ---------- Scope Actions ----------

    def connect_scope(self):
        try:
            idn = self.scope.connect(self.ip_edit.text())
            self.log_msg(f"Connected to scope: {idn.strip()}")
        except Exception as e:
            self.log_msg(str(e))

    def identify_scope(self, checked: bool):
        try:
            self.scope.identify(checked)
        except Exception as e:
            self.log_msg(str(e))

    def open_serial(self):
        port = self.serial_combo.currentData()
        self.serial_thread = SerialReader(port, 115200, self.event_queue)
        self.serial_thread.start()
        self.log_msg(f"Opened serial {port}")

    def closeEvent(self, event):
        if self.serial_thread:
            self.serial_thread.stop()
        event.accept()

    # ---------- Screenshot ----------

    def update_preview_from_png(self, data: bytes):
        pixmap = QPixmap()
        pixmap.loadFromData(data, "PNG")

        self.image_label.setPixmap(
            pixmap.scaled(
                self.image_label.size(),
                Qt.KeepAspectRatio,
                Qt.SmoothTransformation,
            )
        )

    def preview_screenshot(self):
        try:
            data = self.scope.get_screenshot_png(
                color=self.color_cb.isChecked(),
                inverted=self.invert_cb.isChecked(),
            )
            if data is None:
                return
            
            self.update_preview_from_png(data)
            self.log_msg("Screenshot preview updated")

        except Exception as e:
            self.log_msg(str(e))


    def save_screenshot_and_setup(self):
        try:
            # Get Data from Scope
            png_data = self.scope.get_screenshot_png(
                color=self.color_cb.isChecked(),
                inverted=self.invert_cb.isChecked(),
            )

            setup_data = self.scope.get_setup()

            if not png_data or not setup_data:
                self.log_msg("Failed to acquire data from scope")
                return

            # Actualize Preview
            self.update_preview_from_png(png_data)

            # Dialog, Get window to front
            self.showNormal()       # if minimized
            self.raise_()
            self.activateWindow()   # get focus

            filename, _ = QFileDialog.getSaveFileName(
                self, "Save Screenshot", "", "PNG Image (*.png)"
            )

            if not filename:
                return

            if not filename.lower().endswith(".png"):
                filename += ".png"

            # Save PNG + Setup
            with open(filename, "wb") as f:
                f.write(png_data)

            setup_file = filename.replace(".png", ".set")
            with open(setup_file, "wb") as f:
                f.write(setup_data)

            self.log_msg(f"Saved screenshot + setup: {filename}")

        except Exception as e:
            self.log_msg(str(e))


    def load_setup(self):
        filename, _ = QFileDialog.getOpenFileName(
            self, "Load Setup", "", "Setup Files (*.set *.bin)"
        )
        if not filename:
            return

        try:
            with open(filename, "rb") as f:
                data = f.read()

            if self.scope.write_setup_data(data):
                self.log_msg(f"Setup loaded back: {filename}")
            else:
                self.log_msg(f"Failed to load setup: {filename}")

        except Exception as e:
            self.log_msg(str(e))
            
    def footswitch_cell_clicked(self, row, column):
        event_map = {
            (0, 0): "B1S",
            (1, 0): "B1L",
            (0, 1): "BBS",
            (1, 1): "BBL",
            (0, 2): "B2S",
            (1, 2): "B2L",
        }

        event = event_map.get((row, column))
        if event:
            self.handle_event(event)

    # ---------- Event Handling ----------

    def process_events(self):
        while not self.event_queue.empty():
            self.handle_event(self.event_queue.get())

    def handle_event(self, event):
        try:
            if event == "B1S":
                if self.scope.is_running():
                    self.scope.stop()
                    self.log_msg(f"Event {event}: STOP")
                else:
                    self.scope.run()
                    self.log_msg(f"Event {event}: RUN")

            elif event == "B1L":
                self.scope.run()
                self.scope.trigger_auto()
                self.log_msg(f"Event {event}: RUN, TRIGGER AUTO")

            elif event == "B2S":
                self.scope.trigger_normal()
                self.scope.single()
                self.log_msg(f"Event {event}: SINGLE, TRIGGER NORMAL")

            elif event == "B2L":
                self.scope.single()
                self.scope.trigger_force()
                self.log_msg(f"Event {event}: SINGLE, TRIGGER FORCE")

            elif event == "BBS":
                self.preview_screenshot()
                self.log_msg(f"Event {event}: Preview")

            elif event == "BBL":
                self.save_screenshot_and_setup()
                self.log_msg(f"Event {event}: Save PNG + Setup")

        except Exception as e:
            self.log_msg(str(e))

    def log_msg(self, msg):
        self.log.append(msg)

# ----------------------------
# Main
# ----------------------------
if __name__ == "__main__":
    app = QApplication(sys.argv)
    win = MainWindow()
    win.resize(700, 650)
    win.show()
    sys.exit(app.exec())

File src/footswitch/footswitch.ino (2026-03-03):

#define BTN1_PIN 3
#define BTN2_PIN 4

#define DEBOUNCE_MS   30
#define LONGPRESS_MS 800

struct Button {
  uint8_t pin;
  bool stableState;
  bool lastReading;
  unsigned long lastDebounceTime;

  bool pressed;
  bool longSent;
  unsigned long pressTime;
};

Button b1 = {BTN1_PIN, HIGH, HIGH, 0, false, false, 0};
Button b2 = {BTN2_PIN, HIGH, HIGH, 0, false, false, 0};

// --- Combo State ---
bool comboActive = false;
bool comboLongSent = false;
unsigned long comboStartTime = 0;

void setup() {
  pinMode(BTN1_PIN, INPUT_PULLUP);
  pinMode(BTN2_PIN, INPUT_PULLUP);
  Serial.begin(115200);
}

void handleButton(Button &b, const char *shortMsg, const char *longMsg) {
  bool reading = digitalRead(b.pin);

  if (reading != b.lastReading) {
    b.lastDebounceTime = millis();
    b.lastReading = reading;
  }

  if ((millis() - b.lastDebounceTime) > DEBOUNCE_MS) {
    if (reading != b.stableState) {
      b.stableState = reading;

      if (b.stableState == LOW) {
        b.pressed = true;
        b.longSent = false;
        b.pressTime = millis();
      } else {
        if (b.pressed && !b.longSent && !comboActive) {
          Serial.println(shortMsg);
        }
        b.pressed = false;
      }
    }
  }

  // Long press (nur wenn kein Combo läuft)
  if (b.pressed && !b.longSent && !comboActive) {
    if (millis() - b.pressTime >= LONGPRESS_MS) {
      Serial.println(longMsg);
      b.longSent = true;
    }
  }
}

void handleCombo() {

  // Beide stabil gedrückt?
  bool bothPressed = (b1.stableState == LOW && b2.stableState == LOW);

  // Start Combo
  if (bothPressed && !comboActive) {
    comboActive = true;
    comboLongSent = false;
    comboStartTime = millis();

    // Einzel-Long Events blockieren
    b1.longSent = true;
    b2.longSent = true;
  }

  // Während Combo aktiv
  if (comboActive) {

    // Einer losgelassen -> Combo beenden
    if (!bothPressed) {

      if (!comboLongSent) {
        Serial.println("BBS");   // Short Combo
      }

      comboActive = false;
    }
    else {
      // Long Combo
      if (!comboLongSent &&
          (millis() - comboStartTime >= LONGPRESS_MS)) {

        Serial.println("BBL");
        comboLongSent = true;
      }
    }
  }
}

void loop() {
  handleButton(b1, "B1S", "B1L");
  handleButton(b2, "B2S", "B2L");

  handleCombo();
}

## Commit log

2026-02-26 added gitignores for Arduino
2026-02-26 added arduino code and first python script
2026-02-28 added device overview
2026-03-02 applied python script with printscreen
2026-03-03 quick fix for screenshot
    [OsciFootswitch.py]
2026-03-04 corrected trigger moder auto/normal and added force trigger
    [OsciFootswitch.py]
2026-03-04 load back of setup working, and checking if running to switch between stop and run
2026-03-06 corrected commands for Lecroy triggers and screenshot. setup pending
    [OsciFootswitch.py]
2026-03-08 split up individual oscilloscope implementations, added some guards if no device is connected
2026-03-29 documentation cleanup, added hardware circuit
    [arduino_circuit.fzz]
2026-06-26 Added Housing
    [Labor_ScopeFootswitchTrigger.step, OsciFootswitchHousing-BaseBodyBottom.stl, OsciFootswitchHousing-BaseBodyTop.stl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]
2026-06-26 Special handling for Keysight7000 series screendumps. Switched to scope.query_binary_values instead of writing and than reading raw prepared for version 1.2
2026-08-05 Add button capability to table cell to act like footswitch events
2026-08-20 Add 3D view of PCB
2026-08-26 Added fabrication data for PCB. Updated HW documentation with pictures for threaded inserts
2026-08-26 Added notes for screws and nuts
